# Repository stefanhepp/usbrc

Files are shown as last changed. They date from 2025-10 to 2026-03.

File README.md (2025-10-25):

USB RC Receiver
---------------

USB RC receiver to be used as wireless controller for RC flight sims.

Based on ESP32, supports multiple protocols:
* S.BUS (FrSky)
* SRXL2 (Spektrum)

The SRXL2 protocol implementation is based on the SpektrmRC SRXL2 implementation:
https://github.com/SpektrumRC/SRXL2.git

License
-------
Shield: [][cc-by-sa]

This work is licensed under a
[Creative Commons Attribution-ShareAlike 4.0 International License][cc-by-sa].

[][cc-by-sa]

[cc-by-sa]: http://creativecommons.org/licenses/by-sa/4.0/
[cc-by-sa-image]: https://licensebuttons.net/l/by-sa/4.0/88x31.png
[cc-by-sa-shield]: https://img.shields.io/badge/License-CC%20BY--SA%204.0-lightgrey.svg

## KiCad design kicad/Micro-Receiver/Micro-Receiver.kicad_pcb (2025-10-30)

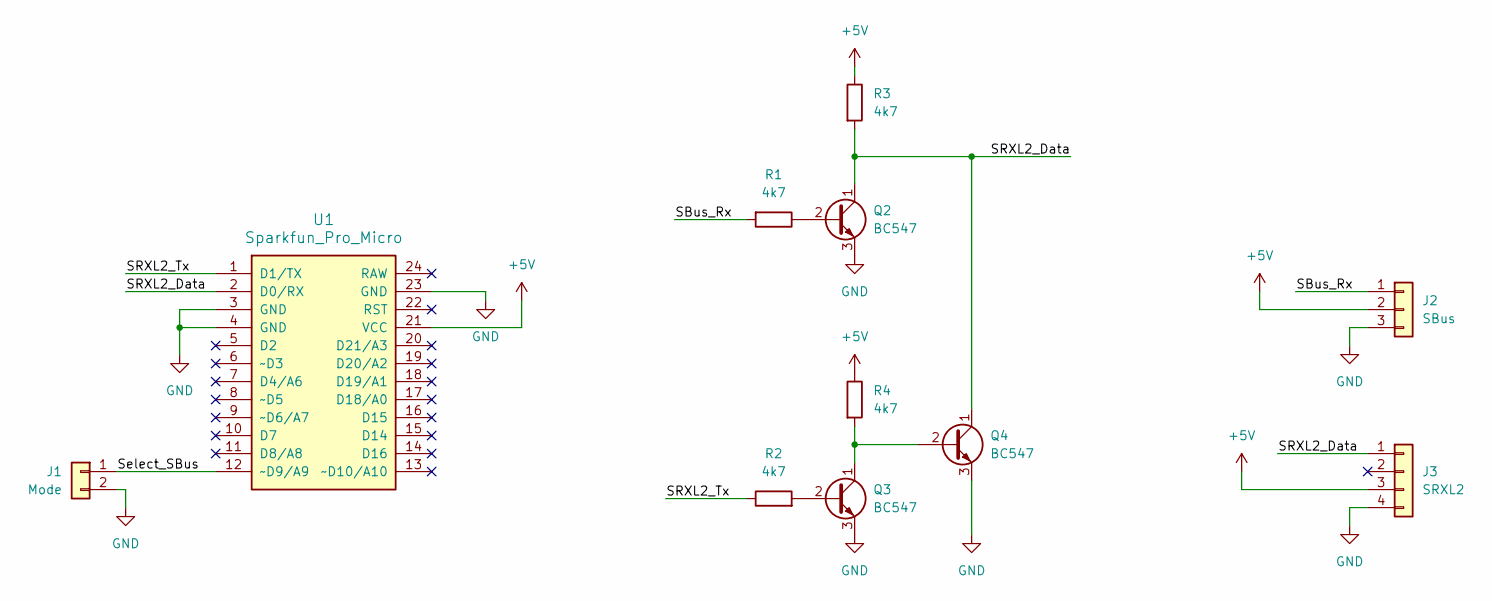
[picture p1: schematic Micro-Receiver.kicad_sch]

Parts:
J1: Mode; PinHeader_1x02_P2.54mm_Vertical
J2: SBus; PinHeader_1x03_P2.54mm_Vertical
J3: SRXL2; PinHeader_1x04_P2.54mm_Vertical
Q2, Q3, Q4: BC547; TO-92L_Inline_Wide
R1, R3, R4: 4k7; R_Axial_DIN0309_L9.0mm_D3.2mm_P5.08mm_Vertical
R2: 4k7; R_Axial_DIN0309_L9.0mm_D3.2mm_P2.54mm_Vertical
U1: Sparkfun_Pro_Micro

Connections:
+5V: J2.2, J3.3, R3.1, R4.1, U1.21 (VCC)
/SBus_Rx: J2.1, R1.2
/SRXL2_Data: J3.1, Q2.1 (C), Q4.1 (C), R3.2, U1.2 (D0/RX)
/SRXL2_Tx: R2.1, U1.1 (D1/TX)
/Select_SBus: J1.1, U1.12 (~D9/A9)
GND: J1.2, J2.3, J3.4, Q2.3 (E), Q3.3 (E), Q4.3 (E), U1.3 (GND), U1.4 (GND), U1.23 (GND)
unnamed: Q2.2 (B), R1.1
unnamed: Q3.2 (B), R2.2
unnamed: Q3.1 (C), Q4.2 (B), R4.2

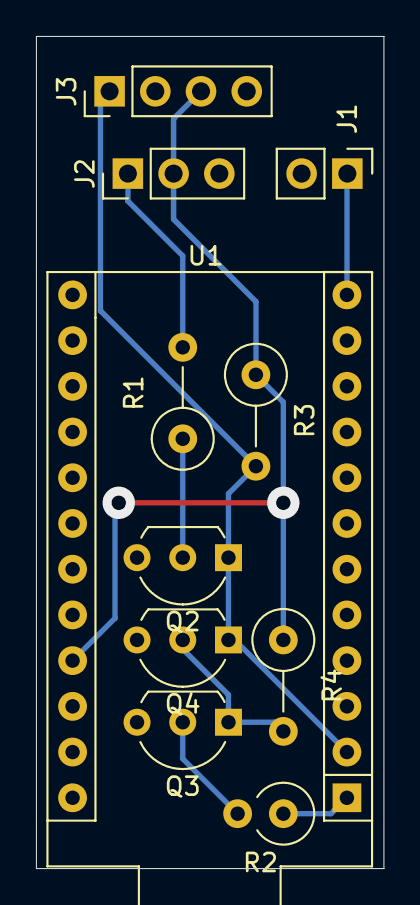
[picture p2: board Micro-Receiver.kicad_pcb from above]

Board: 2 copper layers, 19.3 x 46.2 mm, 11 parts (0 on the bottom side), 9 nets.

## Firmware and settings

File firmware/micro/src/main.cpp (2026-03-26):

// Program used to test the USB Joystick library when used as 
// a Flight Controller on the Arduino Leonardo or Arduino 
// Micro.
//
// Matthew Heironimus
// 2016-05-29 - Original Version
//------------------------------------------------------------

#include <stdint.h>

#include <Joystick.h>
#include <sbus.h>

#include "spm_srxl.h"

/*
 * Setup USB Joystick with 11 axis, 5 buttons.
 */
Joystick_ Joystick(JOYSTICK_DEFAULT_REPORT_ID, 
  JOYSTICK_TYPE_JOYSTICK, 5, 0, 
  true, true, true, true, true, true, 
  true, true, true, true, true);

static const int AXIS_MIN = 0;
static const int AXIS_MAX = 2047; // 65535;
static const int BTN_MID = 1023; // 32768;

static const int PIN_RXLED = 17;
static const int PIN_MODE = 9;

static const uint32_t UniqueID = 0x53652254;
static const int BusID = 0;

static const bool DEBUG = false;

// UART receive buffer
uint8_t rxBuffer[2 * SRXL_MAX_BUFFER_SIZE];
uint8_t rxBufferIndex = 0;

unsigned long lastRxTime = 0;

bool modeSBus = false;

// SBUS object, reading SBUS
bfs::SbusRx sbus_rx(&Serial1);
// SBUS data
bfs::SbusData data;


void uartTransmit(uint8_t uartNum, uint8_t* pBuffer, uint8_t bytesToSend)
{
    Serial1.write(pBuffer, bytesToSend);

    if (DEBUG) {
        Serial.print("W: "); Serial.print(bytesToSend); Serial.print(" -");
        for (int i = 0; i < bytesToSend; i++) {
            Serial.print(" ");
            Serial.print(pBuffer[i], 16);
        }
        Serial.print("\n");
    }
}

// User-defined routine to populate telemetry data
void userProvidedFillSrxlTelemetry(SrxlTelemetryData* pTelemetry)
{
    memset(pTelemetry->raw, 0, 16);
    srxlTelemData.sensorID = 0;
}

// User-defined routine to use the provided channel data from the SRXL bus master
void userProvidedReceivedChannelData(SrxlChannelData* pChannelData, bool isFailsafeData)
{
    if (DEBUG) {
        Serial.print("fail: "); Serial.print(isFailsafeData ? "y" : "n");
        Serial.print(" msk: "); Serial.print(srxlChData.mask, 16); Serial.print(" data: ");
        Serial.print(srxlChData.values[0]); Serial.print(" "); Serial.print(srxlChData.values[1]); Serial.print(" ");
        Serial.print(srxlChData.values[2]); Serial.print(" "); Serial.print(srxlChData.values[3]); Serial.print(" ");
        Serial.print(srxlChData.values[4]); Serial.print(" "); Serial.print(srxlChData.values[5]); Serial.print(" ");
        Serial.print(srxlChData.values[6]); Serial.print(" "); Serial.print(srxlChData.values[7]); Serial.print(" ");
        Serial.print(srxlChData.values[8]); Serial.print(" "); Serial.print(srxlChData.values[9]); Serial.print(" ");
        Serial.print(srxlChData.values[10]); Serial.print(" "); Serial.print(srxlChData.values[11]); Serial.print(" ");
        Serial.print(srxlChData.values[12]); Serial.print(" "); Serial.print(srxlChData.values[13]); Serial.print("\n");
    }

    if (isFailsafeData || srxlChData.mask == 0x00) {
        // Don't send joystick updates when transmitter is not connected
        return;
    }

    if (srxlChData.mask & (1<< 0)) Joystick.setXAxis(srxlChData.values[0] / 32);
    if (srxlChData.mask & (1<< 1)) Joystick.setYAxis(srxlChData.values[1] / 32);
    if (srxlChData.mask & (1<< 2)) Joystick.setZAxis(srxlChData.values[2] / 32);
    if (srxlChData.mask & (1<< 3)) Joystick.setRxAxis(srxlChData.values[3] / 32);
    if (srxlChData.mask & (1<< 4)) Joystick.setRyAxis(srxlChData.values[4] / 32);
    if (srxlChData.mask & (1<< 5)) Joystick.setRzAxis(srxlChData.values[5] / 32);

    if (srxlChData.mask & (1<< 6)) Joystick.setThrottle(srxlChData.values[6] / 32);
    if (srxlChData.mask & (1<< 7)) Joystick.setRudder(srxlChData.values[7] / 32);
    if (srxlChData.mask & (1<< 8)) Joystick.setSteering(srxlChData.values[8] / 32);
    if (srxlChData.mask & (1<< 9)) Joystick.setAccelerator(srxlChData.values[9] / 32);
    if (srxlChData.mask & (1<< 10)) Joystick.setBrake(srxlChData.values[10] / 32);

    if (srxlChData.mask & (1<<11)) Joystick.setButton(0, srxlChData.values[11] < 32768 ? 0 : 1);
    if (srxlChData.mask & (1<<12)) Joystick.setButton(1, srxlChData.values[12] < 32768 ? 0 : 1);
    if (srxlChData.mask & (1<<13)) Joystick.setButton(2, srxlChData.values[13] < 32768 ? 0 : 1);
    if (srxlChData.mask & (1<<14)) Joystick.setButton(3, srxlChData.values[14] < 32768 ? 0 : 1);
    if (srxlChData.mask & (1<<15)) Joystick.setButton(4, srxlChData.values[15] < 32768 ? 0 : 1);

    // RSSI and frame loss data are also available:
    //if(srxlChData.rssi < -85 || (srxlChData.rssi > 0 && srxlChData.rssi < 10))
    //    EnterLongRangeModeForExample();

    Joystick.sendState();

    if (DEBUG) {
        Serial.print("Update Joystick\n");
    }
}

void processSRXL2() {
    if (Serial1.available()) {
        rxBufferIndex += Serial1.readBytes(&rxBuffer[rxBufferIndex], 2*SRXL_MAX_BUFFER_SIZE - rxBufferIndex);
        
        if (DEBUG) {
            Serial.print("R: "); Serial.print(rxBufferIndex); Serial.print(" - ");
            for (int i = 0; i < rxBufferIndex; i++) {
                Serial.print(rxBuffer[i], 16); Serial.print(" ");
            }
            Serial.print("\n");
        }
    }

    // find header
    int frameStart = 0;
    while (rxBuffer[frameStart] != SPEKTRUM_SRXL_ID && frameStart < rxBufferIndex) {
        frameStart++;
    }

    if (frameStart >= rxBufferIndex || frameStart > SRXL_MAX_BUFFER_SIZE) {
        // No header found, or buffer full of garbage. Reset buffer, clear all data
        rxBufferIndex = 0;
        frameStart = 0;
    }

    if (rxBufferIndex - frameStart > 4) {

        // Get length of the message
        int packetLength = rxBuffer[frameStart + 2];

        if (DEBUG) {
            Serial.print("F: "); Serial.print(frameStart); Serial.print(" - "); Serial.print(packetLength); Serial.print("\n");
        }

        if (rxBufferIndex >= packetLength) {
            
            // Try to parse SRXL packet -- this internally calls srxlRun() after packet is parsed and reset timeout
            if(srxlParsePacket(BusID, rxBuffer, packetLength)) {
                digitalWrite(PIN_RXLED, LOW);
                // Move any remaining bytes to beginning of buffer (usually 0)
                rxBufferIndex -= packetLength + frameStart;
                memmove(rxBuffer, &rxBuffer[packetLength + frameStart], rxBufferIndex);

                if (DEBUG) {
                    Serial.print("OK\n");
                }

            } else {
                rxBufferIndex = 0;

                if (DEBUG) {
                    Serial.print("NOK\n");
                }
            }

            // Reset timeout
            lastRxTime = millis();
        }
    }

    // Check for timeout
    unsigned long now = millis();

    if (now < lastRxTime) {
      lastRxTime = 0;
    }
    if (now - lastRxTime >= 5) {
        // Tell SRXL state machine that 5 more milliseconds have passed since packet received
        srxlRun(0, now - lastRxTime);
        rxBufferIndex = 0;
        lastRxTime = now;

        digitalWrite(PIN_RXLED, HIGH);
    }
}

void processSBus() {
    if (sbus_rx.Read()) {
        
        data = sbus_rx.data();
        
        if (DEBUG) {
            for (int8_t i = 0; i < data.NUM_CH; i++) {
                Serial.print(data.ch[i]);
                Serial.print("\t");
            }
            
            Serial.print(data.lost_frame);
            Serial.print("\t");
            Serial.println(data.failsafe);
        }

        Joystick.setXAxis(data.ch[0]);
        Joystick.setYAxis(data.ch[1]);
        Joystick.setZAxis(data.ch[2]);
        Joystick.setRxAxis(data.ch[3]);
        Joystick.setRyAxis(data.ch[4]);
        Joystick.setRzAxis(data.ch[5]);

        Joystick.setThrottle(data.ch[6]);
        Joystick.setRudder(data.ch[7]);
        Joystick.setSteering(data.ch[8]);
        Joystick.setAccelerator(data.ch[9]);
        Joystick.setBrake(data.ch[10]);

        Joystick.setButton(0, data.ch[11] < 1024 ? 0 : 1);
        Joystick.setButton(1, data.ch[12] < 1024 ? 0 : 1);
        Joystick.setButton(2, data.ch[13] < 1024 ? 0 : 1);
        Joystick.setButton(3, data.ch[14] < 1024 ? 0 : 1);
        Joystick.setButton(4, data.ch[15] < 1024 ? 0 : 1);
        
        Joystick.sendState();
    }
}

void setup() {

    pinMode(PIN_RXLED, OUTPUT);

    pinMode(PIN_MODE, INPUT_PULLUP);

    digitalWrite(PIN_RXLED, HIGH);

    modeSBus = (digitalRead(PIN_MODE) == LOW);

    if (modeSBus) {
        sbus_rx.Begin();
    } else {
        Serial1.begin(115200, SERIAL_8N1);
        Serial1.setTimeout(5);

        srxlInitDevice(SRXL_DEVICE_ID, SRXL_DEVICE_PRIORITY, SRXL_DEVICE_INFO, UniqueID);
        srxlInitBus(BusID, 1, SRXL_SUPPORTED_BAUD_RATES);
    }

    Joystick.setXAxisRange(AXIS_MIN, AXIS_MAX);
    Joystick.setYAxisRange(AXIS_MIN, AXIS_MAX);
    Joystick.setZAxisRange(AXIS_MIN, AXIS_MAX);
    Joystick.setRxAxisRange(AXIS_MIN, AXIS_MAX);
    Joystick.setRyAxisRange(AXIS_MIN, AXIS_MAX);
    Joystick.setRzAxisRange(AXIS_MIN, AXIS_MAX);

    Joystick.setRudderRange(AXIS_MIN, AXIS_MAX);
    Joystick.setThrottleRange(AXIS_MIN, AXIS_MAX);
    Joystick.setAcceleratorRange(AXIS_MIN, AXIS_MAX);
    Joystick.setBrakeRange(AXIS_MIN, AXIS_MAX);
    Joystick.setSteeringRange(AXIS_MIN, AXIS_MAX);
    
    Joystick.begin(false);
}

void loop() {

    // Turn indicator light on.
    //digitalWrite(RXLED, (millis() / 1000) % 2);

    if (modeSBus) {
        processSBus();
    } else {
        processSRXL2();
    }

}

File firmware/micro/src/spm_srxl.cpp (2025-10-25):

/*
MIT License

Copyright (c) 2019-2023 Horizon Hobby, LLC

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
THE SOFTWARE IS PROVIDED "AS IS", WITHOUT WARRANTY OF ANY KIND, EXPRESS OR
IMPLIED, INCLUDING BUT NOT LIMITED TO THE WARRANTIES OF MERCHANTABILITY,
FITNESS FOR A PARTICULAR PURPOSE AND NONINFRINGEMENT. IN NO EVENT SHALL THE
AUTHORS OR COPYRIGHT HOLDERS BE LIABLE FOR ANY CLAIM, DAMAGES OR OTHER
LIABILITY, WHETHER IN AN ACTION OF CONTRACT, TORT OR OTHERWISE, ARISING FROM,
OUT OF OR IN CONNECTION WITH THE SOFTWARE OR THE USE OR OTHER DEALINGS IN THE
SOFTWARE.
*/

#include <string.h>
#include <stdint.h>

#include "spm_srxl.h"

/// LOCAL TYPES AND CONSTANTS ///

#if(SRXL_CRC_OPTIMIZE_MODE == SRXL_CRC_OPTIMIZE_SPEED)
const uint16_t srxlCRCTable[] =
{
    0x0000, 0x1021, 0x2042, 0x3063, 0x4084, 0x50A5, 0x60C6, 0x70E7,
    0x8108, 0x9129, 0xA14A, 0xB16B, 0xC18C, 0xD1AD, 0xE1CE, 0xF1EF,
    0x1231, 0x0210, 0x3273, 0x2252, 0x52B5, 0x4294, 0x72F7, 0x62D6,
    0x9339, 0x8318, 0xB37B, 0xA35A, 0xD3BD, 0xC39C, 0xF3FF, 0xE3DE,
    0x2462, 0x3443, 0x0420, 0x1401, 0x64E6, 0x74C7, 0x44A4, 0x5485,
    0xA56A, 0xB54B, 0x8528, 0x9509, 0xE5EE, 0xF5CF, 0xC5AC, 0xD58D,
    0x3653, 0x2672, 0x1611, 0x0630, 0x76D7, 0x66F6, 0x5695, 0x46B4,
    0xB75B, 0xA77A, 0x9719, 0x8738, 0xF7DF, 0xE7FE, 0xD79D, 0xC7BC,

    0x48C4, 0x58E5, 0x6886, 0x78A7, 0x0840, 0x1861, 0x2802, 0x3823,
    0xC9CC, 0xD9ED, 0xE98E, 0xF9AF, 0x8948, 0x9969, 0xA90A, 0xB92B,
    0x5AF5, 0x4AD4, 0x7AB7, 0x6A96, 0x1A71, 0x0A50, 0x3A33, 0x2A12,
    0xDBFD, 0xCBDC, 0xFBBF, 0xEB9E, 0x9B79, 0x8B58, 0xBB3B, 0xAB1A,
    0x6CA6, 0x7C87, 0x4CE4, 0x5CC5, 0x2C22, 0x3C03, 0x0C60, 0x1C41,
    0xEDAE, 0xFD8F, 0xCDEC, 0xDDCD, 0xAD2A, 0xBD0B, 0x8D68, 0x9D49,
    0x7E97, 0x6EB6, 0x5ED5, 0x4EF4, 0x3E13, 0x2E32, 0x1E51, 0x0E70,
    0xFF9F, 0xEFBE, 0xDFDD, 0xCFFC, 0xBF1B, 0xAF3A, 0x9F59, 0x8F78,

    0x9188, 0x81A9, 0xB1CA, 0xA1EB, 0xD10C, 0xC12D, 0xF14E, 0xE16F,
    0x1080, 0x00A1, 0x30C2, 0x20E3, 0x5004, 0x4025, 0x7046, 0x6067,
    0x83B9, 0x9398, 0xA3FB, 0xB3DA, 0xC33D, 0xD31C, 0xE37F, 0xF35E,
    0x02B1, 0x1290, 0x22F3, 0x32D2, 0x4235, 0x5214, 0x6277, 0x7256,
    0xB5EA, 0xA5CB, 0x95A8, 0x8589, 0xF56E, 0xE54F, 0xD52C, 0xC50D,
    0x34E2, 0x24C3, 0x14A0, 0x0481, 0x7466, 0x6447, 0x5424, 0x4405,
    0xA7DB, 0xB7FA, 0x8799, 0x97B8, 0xE75F, 0xF77E, 0xC71D, 0xD73C,
    0x26D3, 0x36F2, 0x0691, 0x16B0, 0x6657, 0x7676, 0x4615, 0x5634,

    0xD94C, 0xC96D, 0xF90E, 0xE92F, 0x99C8, 0x89E9, 0xB98A, 0xA9AB,
    0x5844, 0x4865, 0x7806, 0x6827, 0x18C0, 0x08E1, 0x3882, 0x28A3,
    0xCB7D, 0xDB5C, 0xEB3F, 0xFB1E, 0x8BF9, 0x9BD8, 0xABBB, 0xBB9A,
    0x4A75, 0x5A54, 0x6A37, 0x7A16, 0x0AF1, 0x1AD0, 0x2AB3, 0x3A92,
    0xFD2E, 0xED0F, 0xDD6C, 0xCD4D, 0xBDAA, 0xAD8B, 0x9DE8, 0x8DC9,
    0x7C26, 0x6C07, 0x5C64, 0x4C45, 0x3CA2, 0x2C83, 0x1CE0, 0x0CC1,
    0xEF1F, 0xFF3E, 0xCF5D, 0xDF7C, 0xAF9B, 0xBFBA, 0x8FD9, 0x9FF8,
    0x6E17, 0x7E36, 0x4E55, 0x5E74, 0x2E93, 0x3EB2, 0x0ED1, 0x1EF0
};
#endif

#define SRXL_TELEM_SUPPRESS_MAX (100)

/// PUBLIC VARIABLES ///

SrxlChannelData srxlChData = {0, 0, 0, {0}};
SrxlTelemetryData srxlTelemData = {0};
SrxlVtxData srxlVtxData = {0, 0, 1, 0, 0, 1};

/// LOCAL VARIABLES ///

SrxlDevice srxlThisDev = {0};
SrxlBus srxlBus[SRXL_NUM_OF_BUSES];
bool srxlChDataIsFailsafe = false;
bool srxlTelemetryPhase = false;
uint32_t srxlFailsafeChMask = 0;  // Tracks all active channels for use during failsafe transmission
SrxlBindData srxlBindInfo = {0, 0, 0, 0};
SrxlReceiverStats srxlRx = {0};
uint16_t srxlTelemSuppressCount = 0;

#ifdef SRXL_INCLUDE_FWD_PGM_CODE
SrxlFullID srxlFwdPgmDevice = {0, 0};  // Device that should accept Forward Programming connection by default
uint8_t srxlFwdPgmBuffer[FWD_PGM_MAX_DATA_SIZE] = {0};
uint8_t srxlFwdPgmBufferLength = 0;
#endif

//static uint8_t srxlInternalTest = 0;

// Include additional header and externs if using STM32 hardware acceleration
#if(SRXL_CRC_OPTIMIZE_MODE > SRXL_CRC_OPTIMIZE_SIZE)
#ifdef __cplusplus
extern "C"
{
#endif
#if(SRXL_CRC_OPTIMIZE_MODE == SRXL_CRC_OPTIMIZE_STM_HAL)
#if(SRXL_STM_TARGET_FAMILY == SRXL_STM_TARGET_F7)
#include "stm32f7xx_hal.h"
#else
#include "stm32f3xx_hal.h"  // Default to F3 if not given
#endif
    extern CRC_HandleTypeDef hcrc;
#else
#if(SRXL_STM_TARGET_FAMILY == SRXL_STM_TARGET_F7)
#error "STM32F7 targets not yet supported for register-based STM HW optimization"
#else
#include "stm32f30x.h"  // Default to F3 if not given
#endif
#endif
#ifdef __cplusplus
}
#endif
#endif

/// LOCAL HELPER FUNCTIONS ///

// Compute SRXL CRC over packet buffer (assumes length is correctly set)
static uint16_t srxlCrc16(uint8_t* packet)
{
    uint16_t crc = 0;                // Seed with 0
    uint8_t length = packet[2] - 2;  // Exclude 2 CRC bytes at end of packet from the length

    if(length <= SRXL_MAX_BUFFER_SIZE - 2)
    {
#if(SRXL_CRC_OPTIMIZE_MODE == SRXL_CRC_OPTIMIZE_SIZE)
        // Use bitwise method
        for(uint8_t i = 0; i < length; ++i)
        {
            crc = crc ^ ((uint16_t)packet[i] << 8);
            for(int b = 0; b < 8; b++)
            {
                if(crc & 0x8000)
                    crc = (crc << 1) ^ 0x1021;
                else
                    crc = crc << 1;
            }
        }
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

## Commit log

2025-10-26 Working version with SRXL2 and SBUS on Arduino Micro
    [Micro-Receiver.kicad_pcb, Micro-Receiver.kicad_sch]
2025-10-30 Added schematic and layout for Micro SBus/SRXL adapter
    [Micro-Receiver.kicad_pcb, Micro-Receiver.kicad_sch]
